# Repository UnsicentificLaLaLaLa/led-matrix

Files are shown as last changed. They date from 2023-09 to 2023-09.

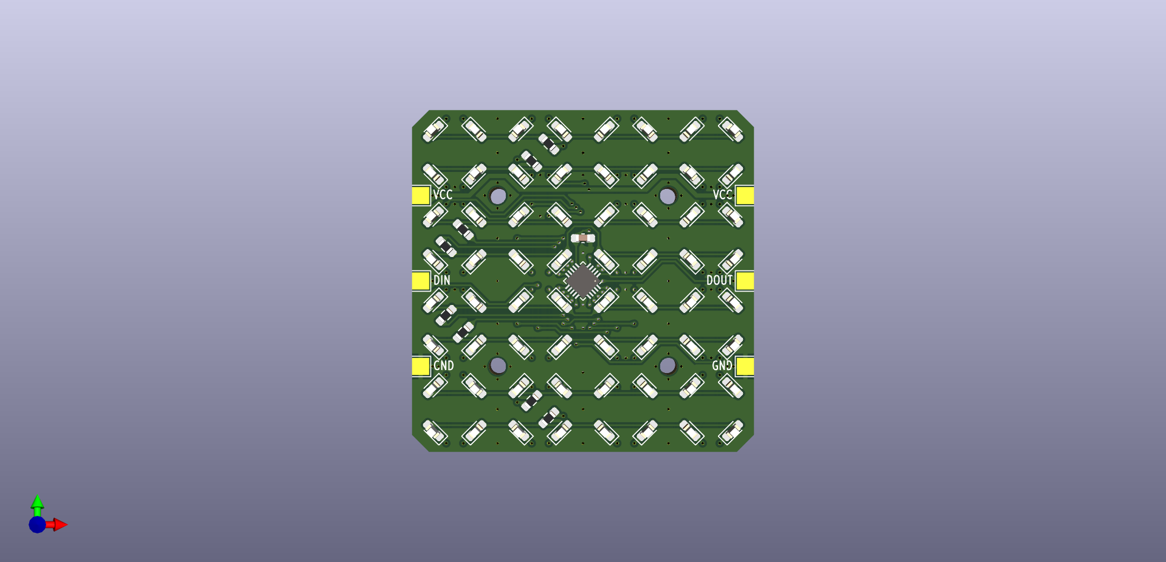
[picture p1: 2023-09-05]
hardware/v1.0/led-matrix.png

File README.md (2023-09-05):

# led-matrix

[TOC]

## 介绍

基于 MM32G0001 设计的 LED 点阵屏模块，可级联，通过串口控制。

## 使用方法

### 单个模块

连接 VCC（3.3 ~ 5V），GND，DIN 引脚连接串口的 TXD。

串口配置为 1000000 波特率，8bit 数据，1停止位，无奇偶校验位。

串口发送 8 个 0xFF，则可以点亮所有 led，发送 8 个 0x00，则会熄灭所有 led。

帧内发送数据的间隔需要小于 1.5ms，每两帧数据之间的间隔需要大于 2ms。

### 多个模块

下一个模块的 VCC 连接 上一个模块的 VCC，GND 连接 GND，DIN 连接 DOUT。第一个模块的连接同单个模块。

串口配置为 1000000 波特率，8bit 数据，1停止位，无奇偶校验位。

串口发送 8\*n 个 0xFF，则可以点亮所有 led，发送 8\*n 个 0x00，则会熄灭所有 led；n 为模块数量。

帧内发送数据的间隔需要小于 1.5ms，每两帧数据之间的间隔需要大于 2ms。

### 更新固件

上电前，保证模块的 DIN 引脚为低电平，然后上电，可进入等待下载固件的状态。

模块背面的 D 触点为 SWDIO，C 为 SWCLK，G 为 GND，使用 SWD 方式下载固件。

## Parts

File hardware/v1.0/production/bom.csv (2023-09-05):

Designator | Footprint | Quantity | Value | LCSC Part #
C1 | 0603 | 1 | 100nF
D1, D10, D11, D12, D13, D14, D15, D16, D17, D18, D19, D2, D20, D21, D22, D23, D24, D25, D26, D27, D28, D29, D3, D30, D31, D32, D33, D34, D35, D36, D37, D38, D39, D4, D40, D41, D42, D43, D44, D45, D46, D47, D48, D49, D5, D50, D51, D52, D53, D54, D55, D56, D57, D58, D59, D6, D60, D61, D62, D63, D64, D7, D8, D9 | 0603 | 64 | LED
H1, H2, H3, H4 | MountingHole_2mm | 4 | M2
J1, J10, J11, J12, J2, J3, J4, J5, J6, J7, J8, J9 | TestPoint_Pad_2.0x2.0mm | 12 | Conn_01x01
R1, R2, R3, R4, R5, R6, R7, R8 | 0603 | 8 | 2K
TP1, TP2, TP3 | TestPoint_Pad_D1.5mm | 3 | TestPoint
U1 | QFN-20-1EP_3x3mm_P0.4mm_EP1.65x1.65mm | 1 | MM32G0001A1N

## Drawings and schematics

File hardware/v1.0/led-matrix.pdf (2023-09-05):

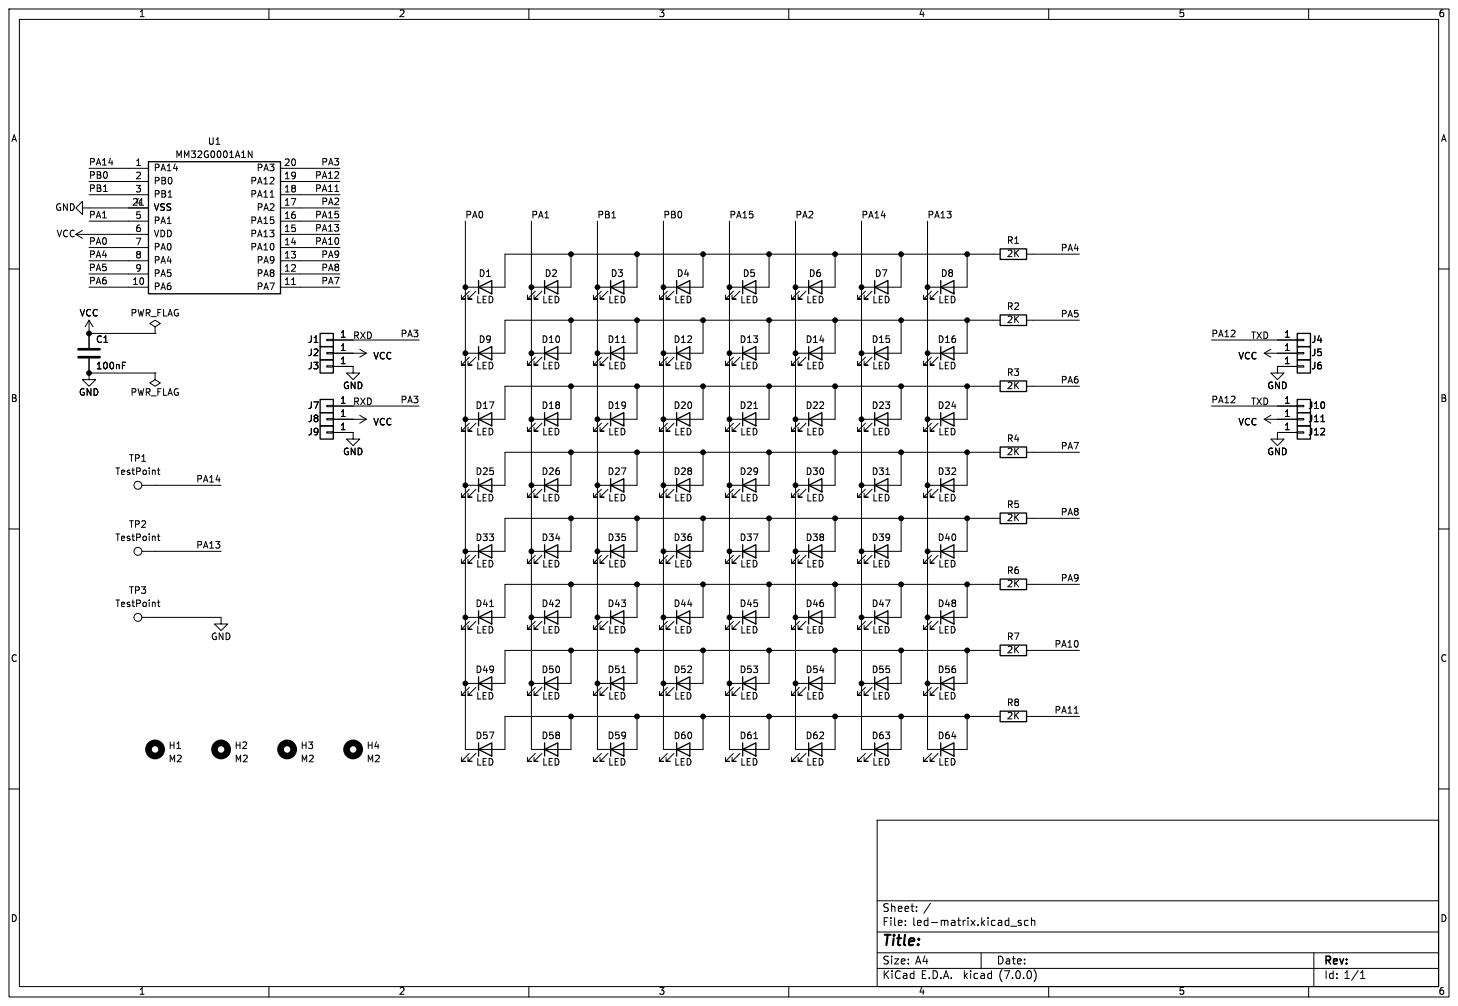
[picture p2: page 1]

Id: 1/1 Title: File: led-matrix.kicad_sch Sheet: / D52

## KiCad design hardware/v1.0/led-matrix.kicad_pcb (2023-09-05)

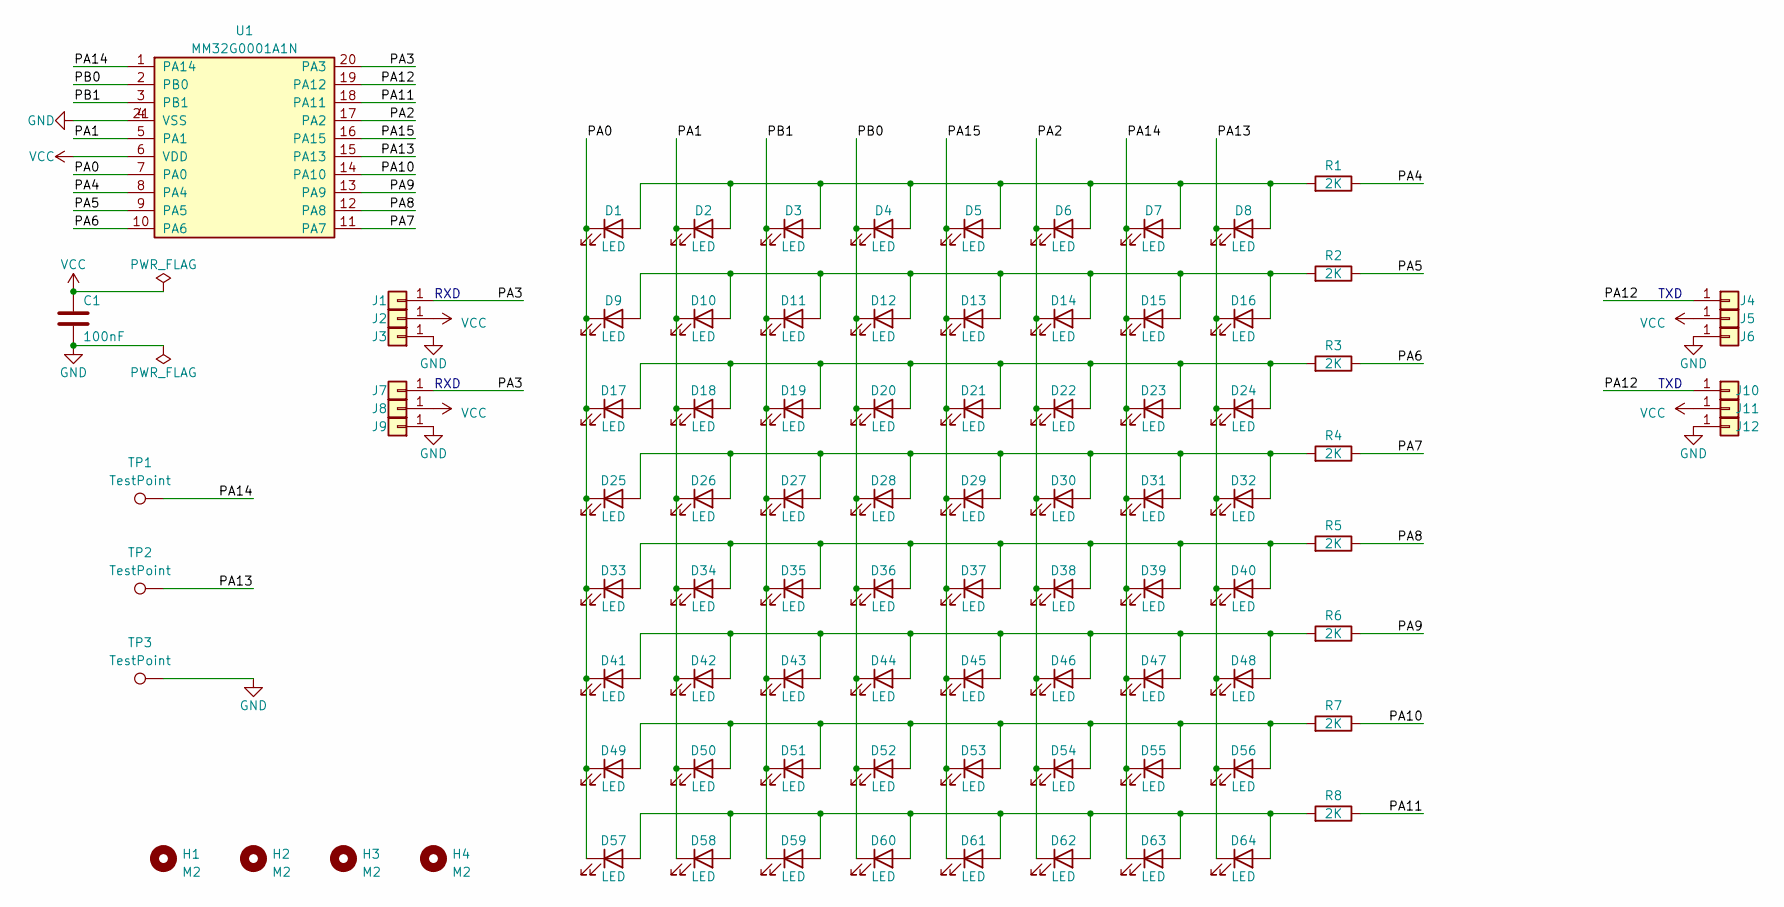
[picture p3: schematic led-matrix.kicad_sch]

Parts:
C1: 100nF; C_0603_1608Metric_Pad1.08x0.95mm_HandSolder
D1, D2, D3, D4, D5, D6, D7, D8, D9, D10, D11, D12, D13, D14, D15, D16, D17, D18, D19, D20, D21, D22, D23, D24, D25, D26, D27, D28, D29, D30, D31, D32, D33, D34, D35, D36, D37, D38, D39, D40, D41, D42, D43, D44, D45, D46, D47, D48, D49, D50, D51, D52, D53, D54, D55, D56, D57, D58, D59, D60, D61, D62, D63, D64: LED; LED_0603_1608Metric_Pad1.05x0.95mm_HandSolder
H1, H2, H3, H4: M2; MountingHole_2mm
J1, J2, J3, J4, J5, J6, J7, J8, J9, J10, J11, J12: Conn_01x01; TestPoint_Pad_2.0x2.0mm
R1, R2, R3, R4, R5, R6, R7, R8: 2K; R_0603_1608Metric_Pad0.98x0.95mm_HandSolder
TP1, TP2, TP3: TestPoint; TestPoint_Pad_D1.5mm
U1: MM32G0001A1N; QFN-20-1EP_3x3mm_P0.4mm_EP1.65x1.65mm

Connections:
/PA0: D1.1 (K), D9.1 (K), D17.1 (K), D25.1 (K), D33.1 (K), D41.1 (K), D49.1 (K), D57.1 (K), U1.7 (PA0)
/PA1: D2.1 (K), D10.1 (K), D18.1 (K), D26.1 (K), D34.1 (K), D42.1 (K), D50.1 (K), D58.1 (K), U1.5 (PA1)
/PA2: D6.1 (K), D14.1 (K), D22.1 (K), D30.1 (K), D38.1 (K), D46.1 (K), D54.1 (K), D62.1 (K), U1.17 (PA2)
/PA3: J1.1, J7.1, U1.20 (PA3)
/PA4: R1.1, U1.8 (PA4)
/PA5: R2.1, U1.9 (PA5)
/PA6: R3.1, U1.10 (PA6)
/PA7: R4.1, U1.11 (PA7)
/PA8: R5.1, U1.12 (PA8)
/PA9: R6.1, U1.13 (PA9)
/PA10: R7.1, U1.14 (PA10)
/PA11: R8.1, U1.18 (PA11)
/PA12: J4.1, J10.1, U1.19 (PA12)
/PA13: D8.1 (K), D16.1 (K), D24.1 (K), D32.1 (K), D40.1 (K), D48.1 (K), D56.1 (K), D64.1 (K), TP2.1, U1.15 (PA13)
/PA14: D7.1 (K), D15.1 (K), D23.1 (K), D31.1 (K), D39.1 (K), D47.1 (K), D55.1 (K), D63.1 (K), TP1.1, U1.1 (PA14)
/PA15: D5.1 (K), D13.1 (K), D21.1 (K), D29.1 (K), D37.1 (K), D45.1 (K), D53.1 (K), D61.1 (K), U1.16 (PA15)
/PB0: D4.1 (K), D12.1 (K), D20.1 (K), D28.1 (K), D36.1 (K), D44.1 (K), D52.1 (K), D60.1 (K), U1.2 (PB0)
/PB1: D3.1 (K), D11.1 (K), D19.1 (K), D27.1 (K), D35.1 (K), D43.1 (K), D51.1 (K), D59.1 (K), U1.3 (PB1)
GND: C1.2, J3.1, J6.1, J9.1, J12.1, TP3.1, U1.4 (VSS), U1.21 (VSS)
unnamed: D1.2 (A), D2.2 (A), D3.2 (A), D4.2 (A), D5.2 (A), D6.2 (A), D7.2 (A), D8.2 (A), R1.2
unnamed: D9.2 (A), D10.2 (A), D11.2 (A), D12.2 (A), D13.2 (A), D14.2 (A), D15.2 (A), D16.2 (A), R2.2
unnamed: D17.2 (A), D18.2 (A), D19.2 (A), D20.2 (A), D21.2 (A), D22.2 (A), D23.2 (A), D24.2 (A), R3.2
unnamed: D25.2 (A), D26.2 (A), D27.2 (A), D28.2 (A), D29.2 (A), D30.2 (A), D31.2 (A), D32.2 (A), R4.2
unnamed: D33.2 (A), D34.2 (A), D35.2 (A), D36.2 (A), D37.2 (A), D38.2 (A), D39.2 (A), D40.2 (A), R5.2
unnamed: D41.2 (A), D42.2 (A), D43.2 (A), D44.2 (A), D45.2 (A), D46.2 (A), D47.2 (A), D48.2 (A), R6.2
unnamed: D49.2 (A), D50.2 (A), D51.2 (A), D52.2 (A), D53.2 (A), D54.2 (A), D55.2 (A), D56.2 (A), R7.2
unnamed: D57.2 (A), D58.2 (A), D59.2 (A), D60.2 (A), D61.2 (A), D62.2 (A), D63.2 (A), D64.2 (A), R8.2
VCC: C1.1, J2.1, J5.1, J8.1, J11.1, U1.6 (VDD)

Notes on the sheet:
RXD
TXD

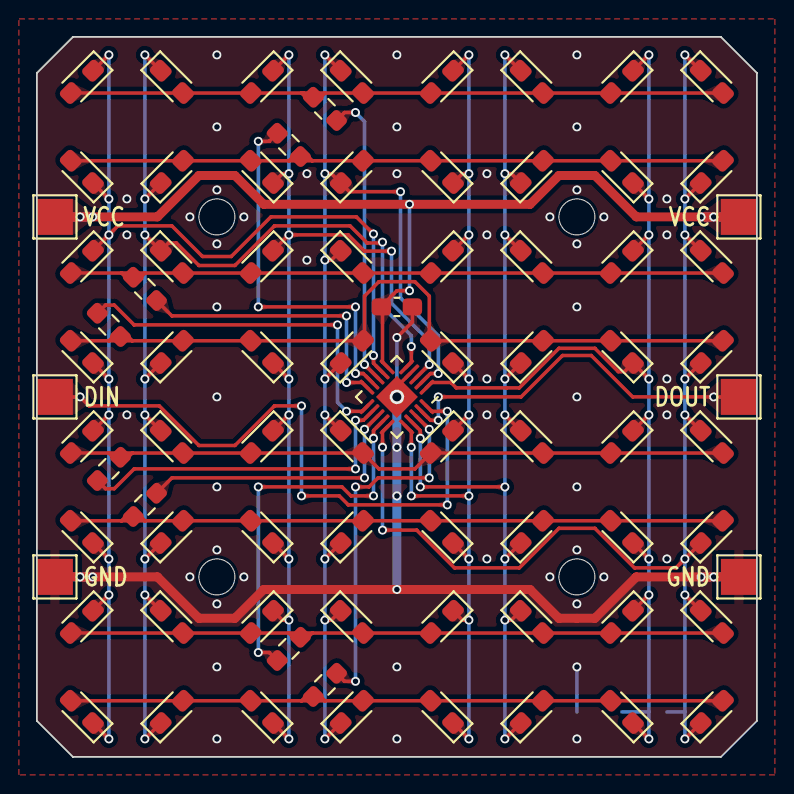
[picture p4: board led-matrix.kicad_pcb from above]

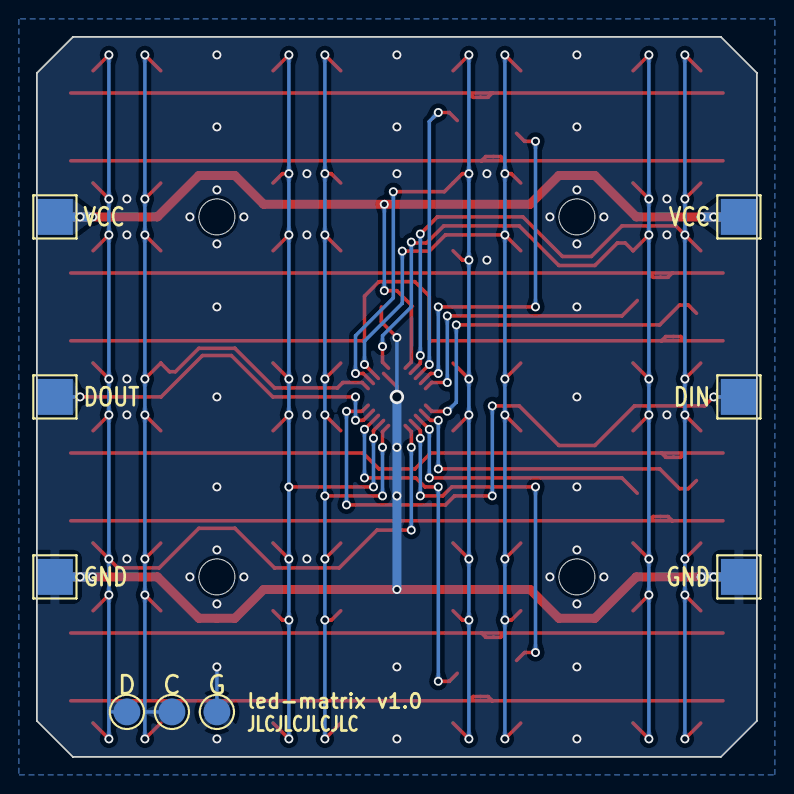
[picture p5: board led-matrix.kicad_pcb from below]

Board: 2 copper layers, 40.0 x 40.0 mm, 93 parts (9 on the bottom side), 28 nets.

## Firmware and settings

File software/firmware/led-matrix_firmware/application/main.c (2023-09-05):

/*
 * MIT License
 *
 * Copyright (c) 2023 UnsicentificLaLaLaLa
 *
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
 */

#include "board_init.h"


uint8_t gram[8] = {0};
volatile uint64_t systime = 0;

struct x_ctrl_if {
    GPIO_Type * port;
    uint32_t    pin;
};

const struct x_ctrl_if x_ctrl_list[8] = {
    {GPIOA, GPIO_PIN_0},
    {GPIOA, GPIO_PIN_1},
    {GPIOB, GPIO_PIN_1},
    {GPIOB, GPIO_PIN_0},
    {GPIOA, GPIO_PIN_15},
    {GPIOA, GPIO_PIN_2},
    {GPIOA, GPIO_PIN_14},
    {GPIOA, GPIO_PIN_13},
};

uint32_t x_ctrl_index = 0;

void led_matrix_init(void);
bool getdata_timeout(uint8_t *val, uint32_t timeout_ms);
void putdata(uint8_t val);

int main(void)
{
    uint8_t ch;

    BOARD_Init();

    printf("hello, world\r\n");
    led_matrix_init();

    uint8_t rx_val = 0;
    while(getdata_timeout(&rx_val, 2))
    {
    }

    uint32_t gram_buf_index = 0;
    while (1)
    {
        if (getdata_timeout(&rx_val, 2))
        {
            if (gram_buf_index == 8)
            {
                putdata(rx_val);
            }
            else
            {
                gram[gram_buf_index] = rx_val;
                gram_buf_index++;
            }
        }
        else
        {
            gram_buf_index = 0;
        }
    }
}

void led_matrix_init(void)
{
    memset(gram, 0, sizeof(gram));
    SysTick_Config(CLOCK_SYS_FREQ / 2000);
}

bool getdata_timeout(uint8_t *val, uint32_t timeout_ms)
{
    uint32_t time_start = systime;
    uint32_t timeout    = time_start + (timeout_ms * 2);

    while(systime < timeout && 0 == (BOARD_DEBUG_USART_PORT->SR & USART_SR_RXNE_MASK))
    {
    }

    if (0 != (BOARD_DEBUG_USART_PORT->SR & USART_SR_RXNE_MASK))
    {
        *val = BOARD_DEBUG_USART_PORT->DR;
        return true;
    }
    else
    {
        return false;
    }
}

void putdata(uint8_t val)
{
    while (0 == (BOARD_DEBUG_USART_PORT->SR & USART_SR_TXE_MASK)) {}
    BOARD_DEBUG_USART_PORT->DR = val;
}

void SysTick_Handler(void)
{
    x_ctrl_list[x_ctrl_index].port->BSRR = x_ctrl_list[x_ctrl_index].pin;
    x_ctrl_index++;
    x_ctrl_index %= 8;

    GPIOA->BRR  = 0xFF << 4;
    GPIOA->BSRR = gram[x_ctrl_index] << 4;

    x_ctrl_list[x_ctrl_index].port->BRR = x_ctrl_list[x_ctrl_index].pin;
    systime++;
}

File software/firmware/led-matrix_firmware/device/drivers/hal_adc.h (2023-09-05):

/*
 * Copyright 2023 MindMotion Microelectronics Co., Ltd.
 * All rights reserved.
 *
 * SPDX-License-Identifier: BSD-3-Clause
 */

#ifndef __HAL_ADC_H__
#define __HAL_ADC_H__

#include "hal_common.h"

/*!
 * @addtogroup ADC
 * @{
 */

/*!
 * @brief ADC driver version number.
 */
#define ADC_DRIVER_VERSION 3u /*!< adc_3. */

/*!
 * @addtogroup ADC_STATUS
 * Define the status of ADC conversion.
 * @{
 */

#define ADC_STATUS_CONV_SEQ_DONE        (1u << 0u) /*!< Status flag when ADC sequence conversion done. */
#define ADC_STATUS_CONV_COMPARE_DONE    (1u << 1u) /*!< Status flag when the ADC conversion result is compared with the set value. */

/*!
 * @}
 */

/*!
 * @addtogroup ADC_INT
 * ADC interrupt define.
 * @{
 */

#define ADC_INT_CONV_SEQ_DONE           (1u << 0u)  /*!< Interrupt enable when ADC sequence conversion done. */
#define ADC_INT_CONV_COMPARE_DONE       (1u << 1u)  /*!< Interrupt enable when ADC the ADC conversion result is compared with the set value. */

/*!
 * @}
 */

/*!
 * @addtogroup ADC_RESULT_FLAGS
 * Define ADC Convert result flags.
 * @{
 */

#define ADC_CONV_RESULT_FLAG_OVERRUN (1u << 0u) /*!< Result flag when adc conversion result is overrun. */
#define ADC_CONV_RESULT_FLAG_VALID   (1u << 1u) /*!< Result flag when adc conversion result valid. */

/*!
 * @}
 */


/*!
 * @brief ADC Resolution type.
 *
 * Select ADC conversion data resolution.
 */
typedef enum
{
    ADC_Resolution_Alt0  = 0u,  /*!< source 0 as a resolution source for ADC. */
    ADC_Resolution_Alt1  = 1u,  /*!< source 1 as a resolution source for ADC. */
    ADC_Resolution_Alt2  = 2u,  /*!< source 2 as a resolution source for ADC. */
    ADC_Resolution_Alt3  = 3u,  /*!< source 3 as a resolution source for ADC. */
    ADC_Resolution_Alt4  = 4u,  /*!< source 4 as a resolution source for ADC. */
} ADC_Resolution_Type;

/*!
 * @brief ADC Prescaler type.
 *
 * Select the prescaler of the bus as the adc clock.
 */
typedef enum
{
    ADC_ClockDiv_2  = 0u,   /*!< ADC clock divided by 2.  */
    ADC_ClockDiv_3  = 1u,   /*!< ADC clock divided by 3.  */
    ADC_ClockDiv_4  = 2u,   /*!< ADC clock divided by 4.  */
    ADC_ClockDiv_5  = 3u,   /*!< ADC clock divided by 5.  */
    ADC_ClockDiv_6  = 4u,   /*!< ADC clock divided by 6.  */
    ADC_ClockDiv_7  = 5u,   /*!< ADC clock divided by 7.  */
    ADC_ClockDiv_8  = 6u,   /*!< ADC clock divided by 8.  */
    ADC_ClockDiv_9  = 7u,   /*!< ADC clock divided by 9.  */
    ADC_ClockDiv_10 = 8u,   /*!< ADC clock divided by 10. */
    ADC_ClockDiv_11 = 9u,   /*!< ADC clock divided by 11. */
    ADC_ClockDiv_12 = 10u,  /*!< ADC clock divided by 12. */
    ADC_ClockDiv_13 = 11u,  /*!< ADC clock divided by 13. */
    ADC_ClockDiv_14 = 12u,  /*!< ADC clock divided by 14. */
    ADC_ClockDiv_15 = 13u,  /*!< ADC clock divided by 15. */
    ADC_ClockDiv_16 = 14u,  /*!< ADC clock divided by 16. */
    ADC_ClockDiv_17 = 15u,  /*!< ADC clock divided by 17. */
} ADC_ClockDiv_Type;

/*!
 * @brief ADC HwTriggerEdge type.
 *
 * Use hardware trigger in ADC.
 */
typedef enum
{
    ADC_HwTriggerEdge_Both     = 0u,   /*!< Both edge trigger.        */
    ADC_HwTriggerEdge_Falling  = 1u,   /*!< Falling edge trigger.     */
    ADC_HwTriggerEdge_Rising   = 2u,   /*!< Rising edge trigger.      */
    ADC_HwTriggerEdge_Disabled = 3u,   /*!< Edge trigger is disabled. */
} ADC_HwTriggerEdge_Type;

/*!
 * @brief ADC HwTriggerDelayCycle type.
 *
 * After the hardware trigger signal is generated, delay N PCLK2 clock cycles before starting the first sample.
 */
typedef enum
{
    ADC_HwTriggerDelayCycle_0   = 0u,    /*!< Delay 0 cycle.    */
    ADC_HwTriggerDelayCycle_4   = 1u,    /*!< Delay 4  cycle.   */
    ADC_HwTriggerDelayCycle_16  = 2u,    /*!< Delay 16 cycle.   */
    ADC_HwTriggerDelayCycle_32  = 3u,    /*!< Delay 32 cycle.   */
    ADC_HwTriggerDelayCycle_64  = 4u,    /*!< Delay 64 cycle.   */
    ADC_HwTriggerDelayCycle_128 = 5u,    /*!< Delay 128 cycle.  */
    ADC_HwTriggerDelayCycle_256 = 6u,    /*!< Delay 256 cycle.  */
    ADC_HwTriggerDelayCycle_512 = 7u,    /*!< Delay 512 cycle.  */
} ADC_HwTriggerDelayCycle_Type;

/*!
 * @brief ADC Align type.
 *
 * Choose to store the converted data as left-aligned or right-aligned.
 */
typedef enum
{
    ADC_Align_Right = 0u,     /*!< Data right align. */
    ADC_Align_Left  = 1u,     /*!< Data left align.  */
} ADC_Align_Type;

/*!
 * @brief ADC ConvMode type.
 *
 * Select the adc channel or sequence convert mode.
 */
typedef enum
{
    ADC_ConvMode_SingleSlot = 0u,    /*!< Run the conversion by channel.  */
    ADC_ConvMode_SeqOneTime = 1u,    /*!< Run the conversion by sequence once. */
    ADC_ConvMode_SeqContinues = 2u,  /*!< Run the conversion by sequence again and again. */
} ADC_ConvMode_Type;

/*!
 * @brief ADC SampleTime type.
 *
 * Sampling time of ADC channel conversion.
 */
typedef enum
{
    ADC_SampleTime_Alt0 = 0u,    /*!< Channel sample time mode  0 . */
    ADC_SampleTime_Alt1 = 1u,    /*!< Channel sample time mode  1 . */
    ADC_SampleTime_Alt2 = 2u,    /*!< Channel sample time mode  2 . */
    ADC_SampleTime_Alt3 = 3u,    /*!< Channel sample time mode  3 . */
    ADC_SampleTime_Alt4 = 4u,    /*!< Channel sample time mode  4 . */
    ADC_SampleTime_Alt5 = 5u,    /*!< Channel sample time mode  5 . */
    ADC_SampleTime_Alt6 = 6u,    /*!< Channel sample time mode  6 . */
    ADC_SampleTime_Alt7 = 7u,    /*!< Channel sample time mode  7 . */
    ADC_SampleTime_Alt8 = 8u,    /*!< Channel sample time mode  8 . */
    ADC_SampleTime_Alt9 = 9u,    /*!< Channel sample time mode  9 . */
    ADC_SampleTime_Alt10 = 10u,  /*!< Channel sample time mode  10. */
    ADC_SampleTime_Alt11 = 11u,  /*!< Channel sample time mode  11. */
    ADC_SampleTime_Alt12 = 12u,  /*!< Channel sample time mode  12. */
    ADC_SampleTime_Alt13 = 13u,  /*!< Channel sample time mode  13. */
    ADC_SampleTime_Alt14 = 14u,  /*!< Channel sample time mode  14. */
    ADC_SampleTime_Alt15 = 15u,  /*!< Channel sample time mode  15. */
} ADC_SampleTime_Type;
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
